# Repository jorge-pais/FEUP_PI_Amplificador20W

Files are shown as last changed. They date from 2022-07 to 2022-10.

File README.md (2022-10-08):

# FEUP PI Amplificador20W
 
20W Audio Amplifier circuit developed for the capstone project of the Bachelor in Electrical and Computer Enginnering course.
The power amplifier features 2 voltage gain stages and a Class AB output stage, along with a DC servo for low output DC offset, a power supply filter featuring a capacitance multiplier and an optional input network.

### PCB Front 3D view
PCBfront

### PCB Rear 3D view
PCBback

## Credits to:
David Rainho\
Gustavo Santos\
Inês Brandão\
Jorge Ribeiro\
Margarida Leal\
Rodrigo Santacomba\
Tiago Ribeiro

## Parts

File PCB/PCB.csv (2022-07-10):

Source: | C:\Users\Jorge Pais\OneDrive\Faculdade\3Ano\S2\ProjetoIntegrador\PCB\PCB.kicad_sch
Date: | 10/07/2022 21:21:08
Tool: | Eeschema (6.0.2)
Generator: | C:\Program Files\KiCad\6.0\bin\scripting\plugins/bom_csv_grouped_by_value.py
Component Count: | 85
Individual Components:
Item | Qty | Reference(s) | Value | LibPart | Footprint | Datasheet
 |  | C1 | 470n | Device:C | Capacitor_THT:C_Rect_L7.2mm_W3.0mm_P5.00mm_FKS2_FKP2_MKS2_MKP2 | ~
 |  | C2 | 100u | Device:C_Polarized | Capacitor_THT:CP_Radial_D5.0mm_P2.00mm | ~
 |  | C3 | 100u | Device:C_Polarized | Capacitor_THT:CP_Radial_D5.0mm_P2.00mm | ~
 |  | C4 | 2p2 | Device:C | Capacitor_THT:C_Disc_D3.8mm_W2.6mm_P2.50mm | ~
 |  | C5 | 100n | Device:C | Capacitor_THT:C_Disc_D5.1mm_W3.2mm_P5.00mm | ~
 |  | C6 | 100n | Device:C | Capacitor_THT:C_Disc_D5.1mm_W3.2mm_P5.00mm | ~
 |  | C7 | 470n | Device:C | Capacitor_THT:C_Rect_L7.2mm_W3.0mm_P5.00mm_FKS2_FKP2_MKS2_MKP2 | ~
 |  | C8 | 100u | Device:C_Polarized | Capacitor_THT:CP_Radial_D8.0mm_P3.50mm | ~
 |  | C9 | 100u | Device:C_Polarized | Capacitor_THT:CP_Radial_D8.0mm_P3.50mm | ~
 |  | C10 | 10u | Device:C_Polarized | Capacitor_THT:CP_Radial_D5.0mm_P2.00mm | ~
 |  | C11 | 10u | Device:C_Polarized | Capacitor_THT:CP_Radial_D5.0mm_P2.00mm | ~
 |  | C12 | 100n | Device:C | Capacitor_THT:C_Disc_D5.1mm_W3.2mm_P5.00mm | ~
 |  | C13 | 100n | Device:C | Capacitor_THT:C_Disc_D5.1mm_W3.2mm_P5.00mm | ~
 |  | C14 | 3n3 | Device:C | Capacitor_THT:C_Rect_L7.2mm_W2.5mm_P5.00mm_FKS2_FKP2_MKS2_MKP2 | ~
 |  | C15 | 10u | Device:C_Polarized | Capacitor_THT:CP_Radial_D5.0mm_P2.00mm | ~
 |  | C16 | 10u | Device:C_Polarized | Capacitor_THT:CP_Radial_D5.0mm_P2.00mm | ~
 |  | C17 | 47p | Device:C | Capacitor_THT:C_Disc_D4.3mm_W1.9mm_P5.00mm | ~
 |  | C18 | 220n | Device:C | Capacitor_THT:C_Rect_L7.0mm_W2.5mm_P5.00mm | ~
 |  | C19 | 100n | Device:C | Capacitor_THT:C_Rect_L13.0mm_W5.0mm_P10.00mm_FKS3_FKP3_MKS4 | ~
 |  | C20 | 100n | Device:C | Capacitor_THT:C_Disc_D5.1mm_W3.2mm_P5.00mm | ~
 |  | C21 | 100n | Device:C | Capacitor_THT:C_Disc_D5.1mm_W3.2mm_P5.00mm | ~
 |  | D1 | 1N914 | Diode:1N914 | Diode_THT:D_DO-35_SOD27_P7.62mm_Horizontal | http://www.vishay.com/docs/85622/1n914.pdf
 |  | D2 | 1N914 | Diode:1N914 | Diode_THT:D_DO-35_SOD27_P7.62mm_Horizontal | http://www.vishay.com/docs/85622/1n914.pdf
 |  | D3 | 1N4148 | Diode:1N4148 | Diode_THT:D_DO-35_SOD27_P7.62mm_Horizontal | https://assets.nexperia.com/documents/data-sheet/1N4148_1N4448.pdf
 |  | D4 | 1N4148 | Diode:1N4148 | Diode_THT:D_DO-35_SOD27_P7.62mm_Horizontal | https://assets.nexperia.com/documents/data-sheet/1N4148_1N4448.pdf
 |  | D5 | 1N4004 | Diode:1N4004 | Diode_THT:D_DO-41_SOD81_P10.16mm_Horizontal | http://www.vishay.com/docs/88503/1n4001.pdf
 |  | D6 | 1N4004 | Diode:1N4004 | Diode_THT:D_DO-41_SOD81_P10.16mm_Horizontal | http://www.vishay.com/docs/88503/1n4001.pdf
 |  | H1 | MountingHole_Pad | Mechanical:MountingHole_Pad | MountingHole:MountingHole_3.2mm_M3_Pad_Via | ~
 |  | H2 | MountingHole_Pad | Mechanical:MountingHole_Pad | MountingHole:MountingHole_3.2mm_M3_Pad_Via | ~
 |  | H3 | MountingHole_Pad | Mechanical:MountingHole_Pad | MountingHole:MountingHole_3.2mm_M3_Pad_Via | ~
 |  | H4 | MountingHole_Pad | Mechanical:MountingHole_Pad | MountingHole:MountingHole_3.2mm_M3_Pad_Via | ~
 |  | J1 | Screw_Terminal_01x03 | Connector:Screw_Terminal_01x03 | TerminalBlock:TerminalBlock_bornier-3_P5.08mm | ~
 |  | J2 | Conn_01x02 | Connector_Generic:Conn_01x02 | Connector_PinHeader_2.54mm:PinHeader_1x02_P2.54mm_Vertical | ~
 |  | J3 | Screw_Terminal_01x02 | Connector:Screw_Terminal_01x02 | TerminalBlock:TerminalBlock_bornier-2_P5.08mm | ~
 |  | Q1 | 2N3904 | Transistor_BJT:2N3904 | Package_TO_SOT_THT:TO-92_Inline | https://www.onsemi.com/pub/Collateral/2N3903-D.PDF
 |  | Q2 | 2N3906 | Transistor_BJT:2N3906 | Package_TO_SOT_THT:TO-92_Inline | https://www.onsemi.com/pub/Collateral/2N3906-D.PDF
 |  | Q3 | 2N4403 | Device:Q_PNP_EBC | Package_TO_SOT_THT:TO-92_Inline | ~
 |  | Q4 | 2N4401 | Device:Q_NPN_EBC | Package_TO_SOT_THT:TO-92_Inline | ~
 |  | Q5 | 2N4403 | Device:Q_PNP_EBC | Package_TO_SOT_THT:TO-92_Inline | ~
 |  | Q6 | 2N4401 | Device:Q_NPN_EBC | Package_TO_SOT_THT:TO-92_Inline | ~
 |  | Q7 | 2N4403 | Device:Q_PNP_EBC | Package_TO_SOT_THT:TO-92_Inline | ~
 |  | Q8 | 2N4403 | Device:Q_PNP_EBC | Package_TO_SOT_THT:TO-92_Inline | ~
 |  | Q9 | 2N4401 | Device:Q_NPN_EBC | Package_TO_SOT_THT:TO-92_Inline | ~
 |  | Q10 | 2N4403 | Device:Q_PNP_EBC | Package_TO_SOT_THT:TO-92_Inline | ~
 |  | Q11 | 2N4401 | Device:Q_NPN_EBC | Package_TO_SOT_THT:TO-92_Inline | ~
 |  | Q12 | 2N4401 | Device:Q_NPN_EBC | Package_TO_SOT_THT:TO-92_Inline | ~
 |  | Q13 | 2N5550 | Device:Q_NPN_EBC | Package_TO_SOT_THT:TO-92_Inline | ~
 |  | Q14 | 2N5401 | Device:Q_PNP_EBC | Package_TO_SOT_THT:TO-92_Inline | ~
 |  | Q15 | MJF15031 | Device:Q_PNP_BCE | Package_TO_SOT_THT:TO-220F-3_Vertical | ~
 |  | Q16 | MJF15030 | Device:Q_NPN_BCE | Package_TO_SOT_THT:TO-220F-3_Vertical | ~
 |  | R1 | 330k | Device:R | Resistor_THT:R_Axial_DIN0207_L6.3mm_D2.5mm_P7.62mm_Horizontal | ~
 |  | R2 | 1k | Device:R | Resistor_THT:R_Axial_DIN0207_L6.3mm_D2.5mm_P7.62mm_Horizontal | ~
 |  | R3 | 10 | Device:R | Resistor_THT:R_Axial_DIN0207_L6.3mm_D2.5mm_P7.62mm_Horizontal | ~
 |  | R4 | 10 | Device:R | Resistor_THT:R_Axial_DIN0207_L6.3mm_D2.5mm_P7.62mm_Horizontal | ~
 |  | R5 | 100 | Device:R | Resistor_THT:R_Axial_DIN0207_L6.3mm_D2.5mm_P7.62mm_Horizontal | ~
 |  | R6 | 8k2 | Device:R | Resistor_THT:R_Axial_DIN0207_L6.3mm_D2.5mm_P7.62mm_Horizontal | ~
 |  | R7 | 330k | Device:R | Resistor_THT:R_Axial_DIN0207_L6.3mm_D2.5mm_P7.62mm_Horizontal | ~
 |  | R8 | 330k | Device:R | Resistor_THT:R_Axial_DIN0207_L6.3mm_D2.5mm_P7.62mm_Horizontal | ~
 |  | R9 | 220 | Device:R | Resistor_THT:R_Axial_DIN0207_L6.3mm_D2.5mm_P7.62mm_Horizontal | ~
 |  | R10 | 22k | Device:R | Resistor_THT:R_Axial_DIN0207_L6.3mm_D2.5mm_P7.62mm_Horizontal | ~
 |  | R11 | 22k | Device:R | Resistor_THT:R_Axial_DIN0207_L6.3mm_D2.5mm_P7.62mm_Horizontal | ~
 |  | R12 | 220 | Device:R | Resistor_THT:R_Axial_DIN0207_L6.3mm_D2.5mm_P7.62mm_Horizontal | ~
 |  | R13 | 100k | Device:R | Resistor_THT:R_Axial_DIN0207_L6.3mm_D2.5mm_P7.62mm_Horizontal | ~
 |  | R14 | 50 | Device:R | Resistor_THT:R_Axial_DIN0207_L6.3mm_D2.5mm_P7.62mm_Horizontal | ~
 |  | R15 | 4.7 | Device:R | Resistor_THT:R_Axial_DIN0207_L6.3mm_D2.5mm_P7.62mm_Horizontal | ~
 |  | R16 | 330 | Device:R | Resistor_THT:R_Axial_DIN0207_L6.3mm_D2.5mm_P7.62mm_Horizontal | ~
 |  | R17 | 180 | Device:R | Resistor_THT:R_Axial_DIN0207_L6.3mm_D2.5mm_P7.62mm_Horizontal | ~
 |  | R18 | 100 | Device:R | Resistor_THT:R_Axial_DIN0207_L6.3mm_D2.5mm_P7.62mm_Horizontal | ~
 |  | R19 | 8k2 | Device:R | Resistor_THT:R_Axial_DIN0207_L6.3mm_D2.5mm_P7.62mm_Horizontal | ~
 |  | R20 | 330 | Device:R | Resistor_THT:R_Axial_DIN0207_L6.3mm_D2.5mm_P7.62mm_Horizontal | ~
 |  | R21 | 180 | Device:R | Resistor_THT:R_Axial_DIN0207_L6.3mm_D2.5mm_P7.62mm_Horizontal | ~
 |  | R22 | 15k | Device:R | Resistor_THT:R_Axial_DIN0207_L6.3mm_D2.5mm_P7.62mm_Horizontal | ~
 |  | R23 | 15k | Device:R | Resistor_THT:R_Axial_DIN0207_L6.3mm_D2.5mm_P7.62mm_Horizontal | ~
 |  | R24 | 820 | Device:R | Resistor_THT:R_Axial_DIN0207_L6.3mm_D2.5mm_P7.62mm_Horizontal | ~
 |  | R25 | 68 | Device:R | Resistor_THT:R_Axial_DIN0207_L6.3mm_D2.5mm_P7.62mm_Horizontal | ~
 |  | R26 | 820 | Device:R | Resistor_THT:R_Axial_DIN0207_L6.3mm_D2.5mm_P7.62mm_Horizontal | ~
 |  | R27 | 390 | Device:R | Resistor_THT:R_Axial_DIN0207_L6.3mm_D2.5mm_P7.62mm_Horizontal | ~
 |  | R28 | 33 | Device:R | Resistor_THT:R_Axial_DIN0207_L6.3mm_D2.5mm_P7.62mm_Horizontal | ~
 |  | R29 | 330 | Device:R | Resistor_THT:R_Axial_DIN0207_L6.3mm_D2.5mm_P7.62mm_Horizontal | ~
 |  | R30 | 330 | Device:R | Resistor_THT:R_Axial_DIN0207_L6.3mm_D2.5mm_P7.62mm_Horizontal | ~
 |  | R31 | 0.22 | Device:R | Resistor_THT:R_Axial_DIN0617_L17.0mm_D6.0mm_P25.40mm_Horizontal | ~
 |  | R32 | 0.22 | Device:R | Resistor_THT:R_Axial_DIN0617_L17.0mm_D6.0mm_P25.40mm_Horizontal | ~
 |  | R33 | 5 | Device:R | Resistor_THT:R_Axial_DIN0617_L17.0mm_D6.0mm_P20.32mm_Horizontal | ~
 |  | RV1 | 1k | Device:R_Potentiometer | Potentiometer_THT:Potentiometer_Bourns_3296W_Vertical | ~
 |  | U1 | OPA1641 | Amplifier_Operational:OPA1641 | Package_SO:SOIC-8_3.9x4.9mm_P1.27mm | http://www.ti.com/lit/ds/symlink/opa1641.pdf
Collated Components:
Item | Qty | Reference(s) | Value | LibPart | Footprint | Datasheet
1 | 2 | C1, C7 | 470n | Device:C | Capacitor_THT:C_Rect_L7.2mm_W3.0mm_P5.00mm_FKS2_FKP2_MKS2_MKP2 | ~
2 | 2 | C2, C3 | 100u | Device:C_Polarized | Capacitor_THT:CP_Radial_D5.0mm_P2.00mm | ~
3 | 1 | C4 | 2p2 | Device:C | Capacitor_THT:C_Disc_D3.8mm_W2.6mm_P2.50mm | ~
4 | 6 | C5, C6, C12, C13, C20, C21 | 100n | Device:C | Capacitor_THT:C_Disc_D5.1mm_W3.2mm_P5.00mm | ~
5 | 2 | C8, C9 | 100u | Device:C_Polarized | Capacitor_THT:CP_Radial_D8.0mm_P3.50mm | ~
6 | 4 | C10, C11, C15, C16 | 10u | Device:C_Polarized | Capacitor_THT:CP_Radial_D5.0mm_P2.00mm | ~
7 | 1 | C14 | 3n3 | Device:C | Capacitor_THT:C_Rect_L7.2mm_W2.5mm_P5.00mm_FKS2_FKP2_MKS2_MKP2 | ~
8 | 1 | C17 | 47p | Device:C | Capacitor_THT:C_Disc_D4.3mm_W1.9mm_P5.00mm | ~
9 | 1 | C18 | 220n | Device:C | Capacitor_THT:C_Rect_L7.0mm_W2.5mm_P5.00mm | ~
10 | 1 | C19 | 100n | Device:C | Capacitor_THT:C_Rect_L13.0mm_W5.0mm_P10.00mm_FKS3_FKP3_MKS4 | ~
11 | 2 | D1, D2 | 1N914 | Diode:1N914 | Diode_THT:D_DO-35_SOD27_P7.62mm_Horizontal | http://www.vishay.com/docs/85622/1n914.pdf
12 | 2 | D3, D4 | 1N4148 | Diode:1N4148 | Diode_THT:D_DO-35_SOD27_P7.62mm_Horizontal | https://assets.nexperia.com/documents/data-sheet/1N4148_1N4448.pdf
13 | 2 | D5, D6 | 1N4004 | Diode:1N4004 | Diode_THT:D_DO-41_SOD81_P10.16mm_Horizontal | http://www.vishay.com/docs/88503/1n4001.pdf
14 | 4 | H1, H2, H3, H4 | MountingHole_Pad | Mechanical:MountingHole_Pad | MountingHole:MountingHole_3.2mm_M3_Pad_Via | ~
15 | 1 | J1 | Screw_Terminal_01x03 | Connector:Screw_Terminal_01x03 | TerminalBlock:TerminalBlock_bornier-3_P5.08mm | ~
16 | 1 | J2 | Conn_01x02 | Connector_Generic:Conn_01x02 | Connector_PinHeader_2.54mm:PinHeader_1x02_P2.54mm_Vertical | ~
17 | 1 | J3 | Screw_Terminal_01x02 | Connector:Screw_Terminal_01x02 | TerminalBlock:TerminalBlock_bornier-2_P5.08mm | ~
18 | 1 | Q1 | 2N3904 | Transistor_BJT:2N3904 | Package_TO_SOT_THT:TO-92_Inline | https://www.onsemi.com/pub/Collateral/2N3903-D.PDF
19 | 1 | Q2 | 2N3906 | Transistor_BJT:2N3906 | Package_TO_SOT_THT:TO-92_Inline | https://www.onsemi.com/pub/Collateral/2N3906-D.PDF
20 | 5 | Q3, Q5, Q7, Q8, Q10 | 2N4403 | Device:Q_PNP_EBC | Package_TO_SOT_THT:TO-92_Inline | ~
21 | 5 | Q4, Q6, Q9, Q11, Q12 | 2N4401 | Device:Q_NPN_EBC | Package_TO_SOT_THT:TO-92_Inline | ~
22 | 1 | Q13 | 2N5550 | Device:Q_NPN_EBC | Package_TO_SOT_THT:TO-92_Inline | ~
23 | 1 | Q14 | 2N5401 | Device:Q_PNP_EBC | Package_TO_SOT_THT:TO-92_Inline | ~
24 | 1 | Q15 | MJF15031 | Device:Q_PNP_BCE | Package_TO_SOT_THT:TO-220F-3_Vertical | ~
25 | 1 | Q16 | MJF15030 | Device:Q_NPN_BCE | Package_TO_SOT_THT:TO-220F-3_Vertical | ~
26 | 3 | R1, R7, R8 | 330k | Device:R | Resistor_THT:R_Axial_DIN0207_L6.3mm_D2.5mm_P7.62mm_Horizontal | ~
27 | 1 | R2 | 1k | Device:R | Resistor_THT:R_Axial_DIN0207_L6.3mm_D2.5mm_P7.62mm_Horizontal | ~
28 | 2 | R3, R4 | 10 | Device:R | Resistor_THT:R_Axial_DIN0207_L6.3mm_D2.5mm_P7.62mm_Horizontal | ~
29 | 2 | R5, R18 | 100 | Device:R | Resistor_THT:R_Axial_DIN0207_L6.3mm_D2.5mm_P7.62mm_Horizontal | ~
30 | 2 | R6, R19 | 8k2 | Device:R | Resistor_THT:R_Axial_DIN0207_L6.3mm_D2.5mm_P7.62mm_Horizontal | ~
31 | 2 | R9, R12 | 220 | Device:R | Resistor_THT:R_Axial_DIN0207_L6.3mm_D2.5mm_P7.62mm_Horizontal | ~
32 | 2 | R10, R11 | 22k | Device:R | Resistor_THT:R_Axial_DIN0207_L6.3mm_D2.5mm_P7.62mm_Horizontal | ~
33 | 1 | R13 | 100k | Device:R | Resistor_THT:R_Axial_DIN0207_L6.3mm_D2.5mm_P7.62mm_Horizontal | ~
34 | 1 | R14 | 50 | Device:R | Resistor_THT:R_Axial_DIN0207_L6.3mm_D2.5mm_P7.62mm_Horizontal | ~
35 | 1 | R15 | 4.7 | Device:R | Resistor_THT:R_Axial_DIN0207_L6.3mm_D2.5mm_P7.62mm_Horizontal | ~
36 | 4 | R16, R20, R29, R30 | 330 | Device:R | Resistor_THT:R_Axial_DIN0207_L6.3mm_D2.5mm_P7.62mm_Horizontal | ~
37 | 2 | R17, R21 | 180 | Device:R | Resistor_THT:R_Axial_DIN0207_L6.3mm_D2.5mm_P7.62mm_Horizontal | ~
38 | 2 | R22, R23 | 15k | Device:R | Resistor_THT:R_Axial_DIN0207_L6.3mm_D2.5mm_P7.62mm_Horizontal | ~
39 | 2 | R24, R26 | 820 | Device:R | Resistor_THT:R_Axial_DIN0207_L6.3mm_D2.5mm_P7.62mm_Horizontal | ~
40 | 1 | R25 | 68 | Device:R | Resistor_THT:R_Axial_DIN0207_L6.3mm_D2.5mm_P7.62mm_Horizontal | ~
41 | 1 | R27 | 390 | Device:R | Resistor_THT:R_Axial_DIN0207_L6.3mm_D2.5mm_P7.62mm_Horizontal | ~
42 | 1 | R28 | 33 | Device:R | Resistor_THT:R_Axial_DIN0207_L6.3mm_D2.5mm_P7.62mm_Horizontal | ~
43 | 2 | R31, R32 | 0.22 | Device:R | Resistor_THT:R_Axial_DIN0617_L17.0mm_D6.0mm_P25.40mm_Horizontal | ~
44 | 1 | R33 | 5 | Device:R | Resistor_THT:R_Axial_DIN0617_L17.0mm_D6.0mm_P20.32mm_Horizontal | ~
45 | 1 | RV1 | 1k | Device:R_Potentiometer | Potentiometer_THT:Potentiometer_Bourns_3296W_Vertical | ~
46 | 1 | U1 | OPA1641 | Amplifier_Operational:OPA1641 | Package_SO:SOIC-8_3.9x4.9mm_P1.27mm | http://www.ti.com/lit/ds/symlink/opa1641.pdf

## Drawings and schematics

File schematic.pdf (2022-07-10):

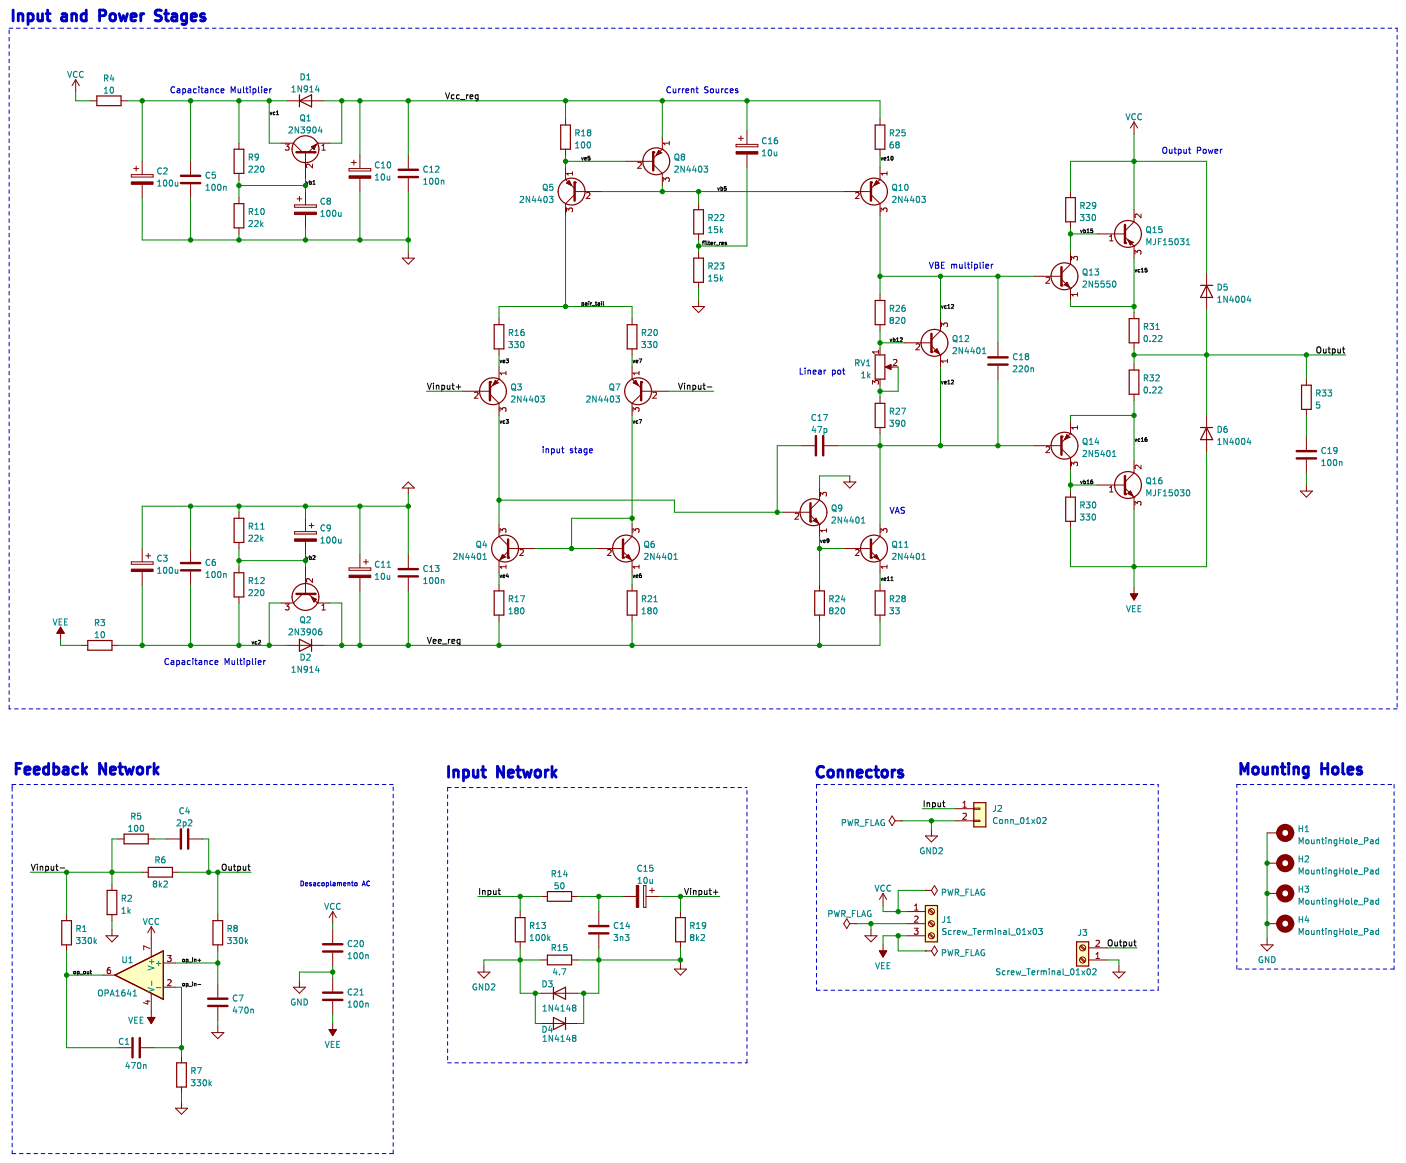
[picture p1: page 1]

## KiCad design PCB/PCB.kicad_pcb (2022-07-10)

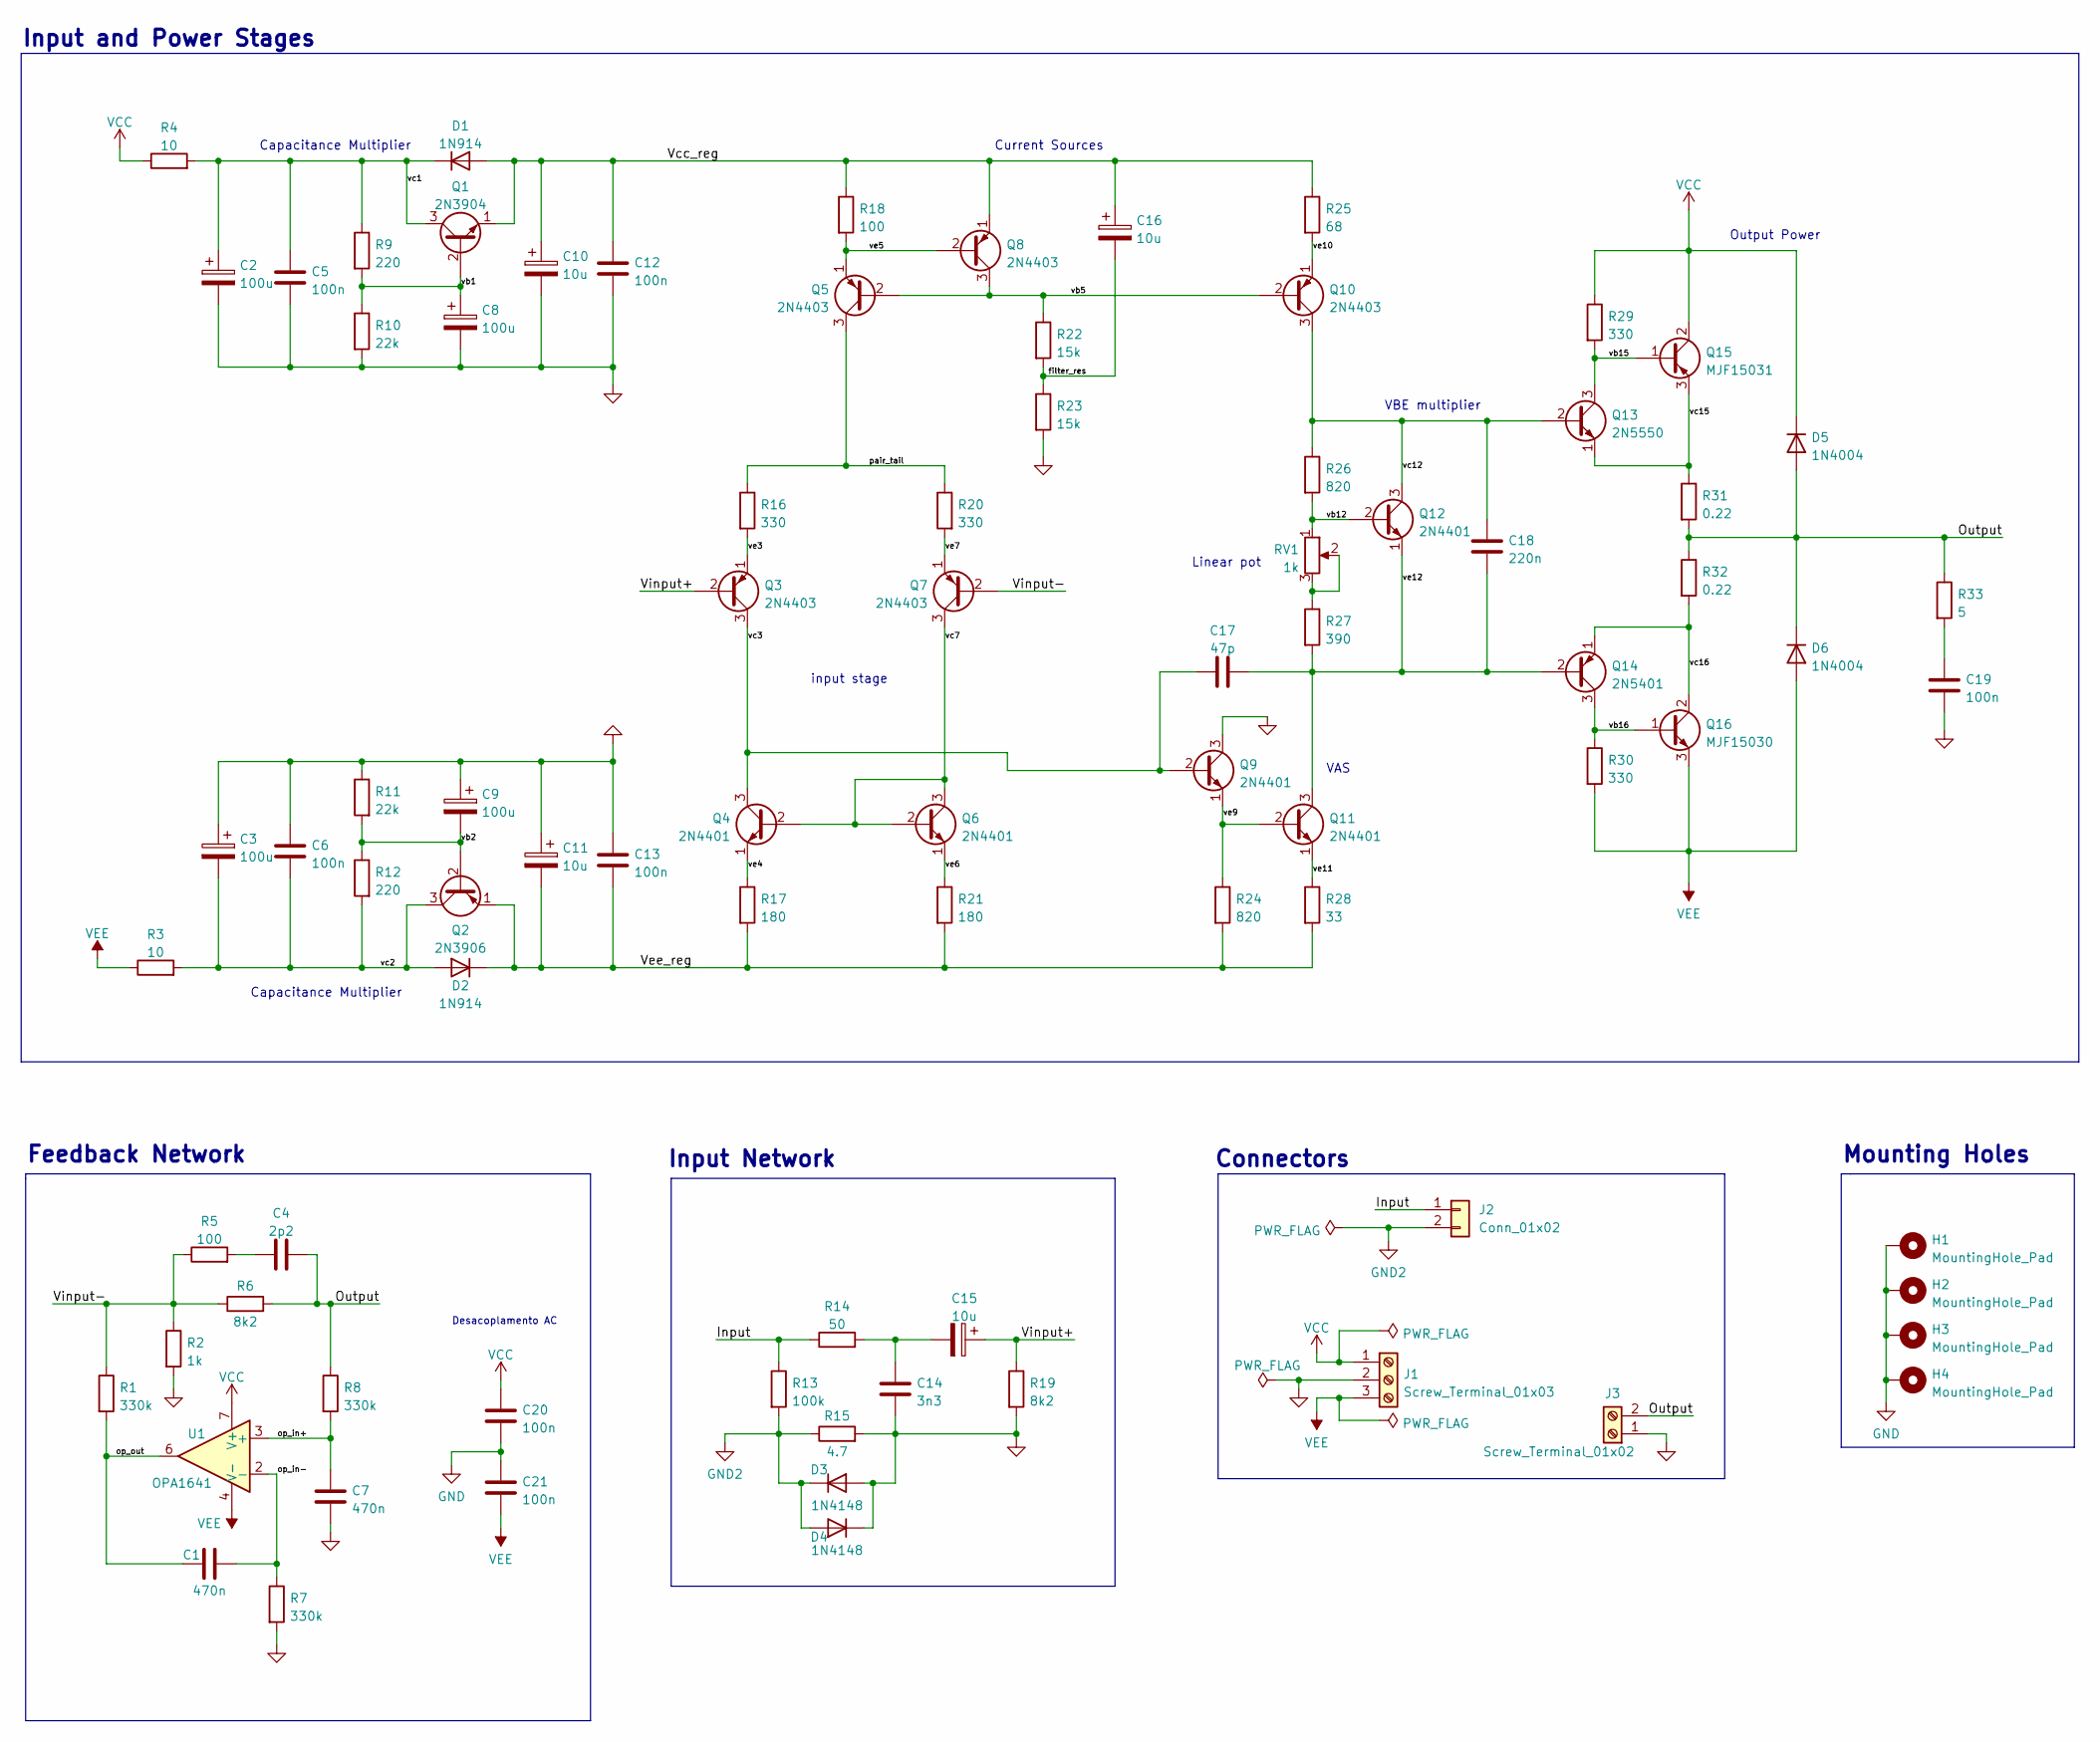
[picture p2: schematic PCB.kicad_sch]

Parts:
C1, C7: 470n; C_Rect_L7.2mm_W3.0mm_P5.00mm_FKS2_FKP2_MKS2_MKP2
C2, C3: 100u; CP_Radial_D5.0mm_P2.00mm
C4: 2p2; C_Disc_D3.8mm_W2.6mm_P2.50mm
C5, C6, C12, C13, C20, C21: 100n; C_Disc_D5.1mm_W3.2mm_P5.00mm
C8, C9: 100u; CP_Radial_D8.0mm_P3.50mm
C10, C11, C15, C16: 10u; CP_Radial_D5.0mm_P2.00mm
C14: 3n3; C_Rect_L7.2mm_W2.5mm_P5.00mm_FKS2_FKP2_MKS2_MKP2
C17: 47p; C_Disc_D4.3mm_W1.9mm_P5.00mm
C18: 220n; C_Rect_L7.0mm_W2.5mm_P5.00mm
C19: 100n; C_Rect_L13.0mm_W5.0mm_P10.00mm_FKS3_FKP3_MKS4
D1, D2: 1N914; D_DO-35_SOD27_P7.62mm_Horizontal
D3, D4: 1N4148; D_DO-35_SOD27_P7.62mm_Horizontal
D5, D6: 1N4004; D_DO-41_SOD81_P10.16mm_Horizontal
H1, H2, H3, H4: MountingHole_Pad; MountingHole_3.2mm_M3_Pad_Via
J1: Screw_Terminal_01x03; TerminalBlock_bornier-3_P5.08mm
J2: Conn_01x02; PinHeader_1x02_P2.54mm_Vertical
J3: Screw_Terminal_01x02; TerminalBlock_bornier-2_P5.08mm
Q1: 2N3904; TO-92_Inline
Q2: 2N3906; TO-92_Inline
Q3, Q5, Q7, Q8, Q10: 2N4403; TO-92_Inline
Q4, Q6, Q9, Q11, Q12: 2N4401; TO-92_Inline
Q13: 2N5550; TO-92_Inline
Q14: 2N5401; TO-92_Inline
Q15: MJF15031; TO-220F-3_Vertical
Q16: MJF15030; TO-220F-3_Vertical
R1, R7, R8: 330k; R_Axial_DIN0207_L6.3mm_D2.5mm_P7.62mm_Horizontal
R2: 1k; R_Axial_DIN0207_L6.3mm_D2.5mm_P7.62mm_Horizontal
R3, R4: 10; R_Axial_DIN0207_L6.3mm_D2.5mm_P7.62mm_Horizontal
R5, R18: 100; R_Axial_DIN0207_L6.3mm_D2.5mm_P7.62mm_Horizontal
R6, R19: 8k2; R_Axial_DIN0207_L6.3mm_D2.5mm_P7.62mm_Horizontal
R9, R12: 220; R_Axial_DIN0207_L6.3mm_D2.5mm_P7.62mm_Horizontal
R10, R11: 22k; R_Axial_DIN0207_L6.3mm_D2.5mm_P7.62mm_Horizontal
R13: 100k; R_Axial_DIN0207_L6.3mm_D2.5mm_P7.62mm_Horizontal
R14: 50; R_Axial_DIN0207_L6.3mm_D2.5mm_P7.62mm_Horizontal
R15: 4.7; R_Axial_DIN0207_L6.3mm_D2.5mm_P7.62mm_Horizontal
R16, R20, R29, R30: 330; R_Axial_DIN0207_L6.3mm_D2.5mm_P7.62mm_Horizontal
R17, R21: 180; R_Axial_DIN0207_L6.3mm_D2.5mm_P7.62mm_Horizontal
R22, R23: 15k; R_Axial_DIN0207_L6.3mm_D2.5mm_P7.62mm_Horizontal
R24, R26: 820; R_Axial_DIN0207_L6.3mm_D2.5mm_P7.62mm_Horizontal
R25: 68; R_Axial_DIN0207_L6.3mm_D2.5mm_P7.62mm_Horizontal
R27: 390; R_Axial_DIN0207_L6.3mm_D2.5mm_P7.62mm_Horizontal
R28: 33; R_Axial_DIN0207_L6.3mm_D2.5mm_P7.62mm_Horizontal
R31, R32: 0.22; R_Axial_DIN0617_L17.0mm_D6.0mm_P25.40mm_Horizontal
R33: 5; R_Axial_DIN0617_L17.0mm_D6.0mm_P20.32mm_Horizontal
RV1: 1k; Potentiometer_Bourns_3296W_Vertical
U1: OPA1641; SOIC-8_3.9x4.9mm_P1.27mm

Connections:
/Input: J2.1, R13.1, R14.1
/Output: C4.2, D5.2 (A), D6.1 (K), J3.2, R6.2, R8.1, R31.2, R32.1, R33.1
/Vcc_reg: C10.1, C12.1, C16.1, D1.2 (A), Q1.1 (E), Q8.1 (E), R18.1, R25.1
/Vee_reg: C11.2, C13.2, D2.1 (K), Q2.1 (E), R17.2, R21.2, R24.2, R28.2
/Vinput+: C15.1, Q3.2 (B), R19.1
/Vinput-: Q7.2 (B), R1.1, R2.1, R5.1, R6.1
/filter_res: C16.2, R22.2, R23.1
/op_in+: C7.1, R8.2, U1.3 (+)
/op_in-: C1.2, R7.1, U1.2 (-)
/op_out: C1.1, R1.2, U1.6
/pair_tail: Q5.3 (C), R16.1, R20.1
/vb1: C8.1, Q1.2 (B), R9.2, R10.1
/vb2: C9.2, Q2.2 (B), R11.2, R12.1
/vb5: Q5.2 (B), Q8.3 (C), Q10.2 (B), R22.1
/vb12: Q12.2 (B), R26.2, RV1.1
/vb15: Q13.3 (C), Q15.1 (B), R29.2
/vb16: Q14.3 (C), Q16.1 (B), R30.1
/vc1: C2.1, C5.1, D1.1 (K), Q1.3 (C), R4.2, R9.1
/vc2: C3.2, C6.2, D2.2 (A), Q2.3 (C), R3.2, R12.2
/vc3: C17.1, Q3.3 (C), Q4.3 (C), Q9.2 (B)
/vc7: Q4.2 (B), Q6.2 (B), Q6.3 (C), Q7.3 (C)
/vc12: C18.1, Q10.3 (C), Q12.3 (C), Q13.2 (B), R26.1
/vc15: Q13.1 (E), Q15.3 (E), R31.1
/vc16: Q14.1 (E), Q16.2 (C), R32.2
/ve3: Q3.1 (E), R16.2
/ve4: Q4.1 (E), R17.1
/ve5: Q5.1 (E), Q8.2 (B), R18.2
/ve6: Q6.1 (E), R21.1
/ve7: Q7.1 (E), R20.2
/ve9: Q9.1 (E), Q11.2 (B), R24.1
/ve10: Q10.1 (E), R25.2
/ve11: Q11.1 (E), R28.1
/ve12: C17.2, C18.2, Q11.3 (C), Q12.1 (E), Q14.2 (B), R27.2
GND: C2.2, C3.1, C5.2, C6.1, C7.2, C8.2, C9.1, C10.2, C11.1, C12.2, C13.1, C14.2, C19.2, C20.2, C21.1, D3.2 (A), D4.1 (K), H1.1, H2.1, H3.1, H4.1, J1.2, J3.1, Q9.3 (C), R2.2, R7.2, R10.2, R11.1, R15.2, R19.2, R23.2
GND2: D3.1 (K), D4.2 (A), J2.2, R13.2, R15.1
unnamed: C4.1, R5.2
unnamed: C14.1, C15.2, R14.2
unnamed: C19.1, R33.2
unnamed: R27.1, RV1.2, RV1.3
VCC: C20.1, D5.1 (K), J1.1, Q15.2 (C), R4.1, R29.1, U1.7 (V+)
VEE: C21.2, D6.2 (A), J1.3, Q16.3 (E), R3.1, R30.2, U1.4 (V-)

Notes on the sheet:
Feedback Network
Mounting Holes
Desacoplamento AC
Output Power
input stage
Capacitance Multiplier
VAS
Input and Power Stages
VBE multiplier
Connectors
Input Network
Current Sources
Linear pot

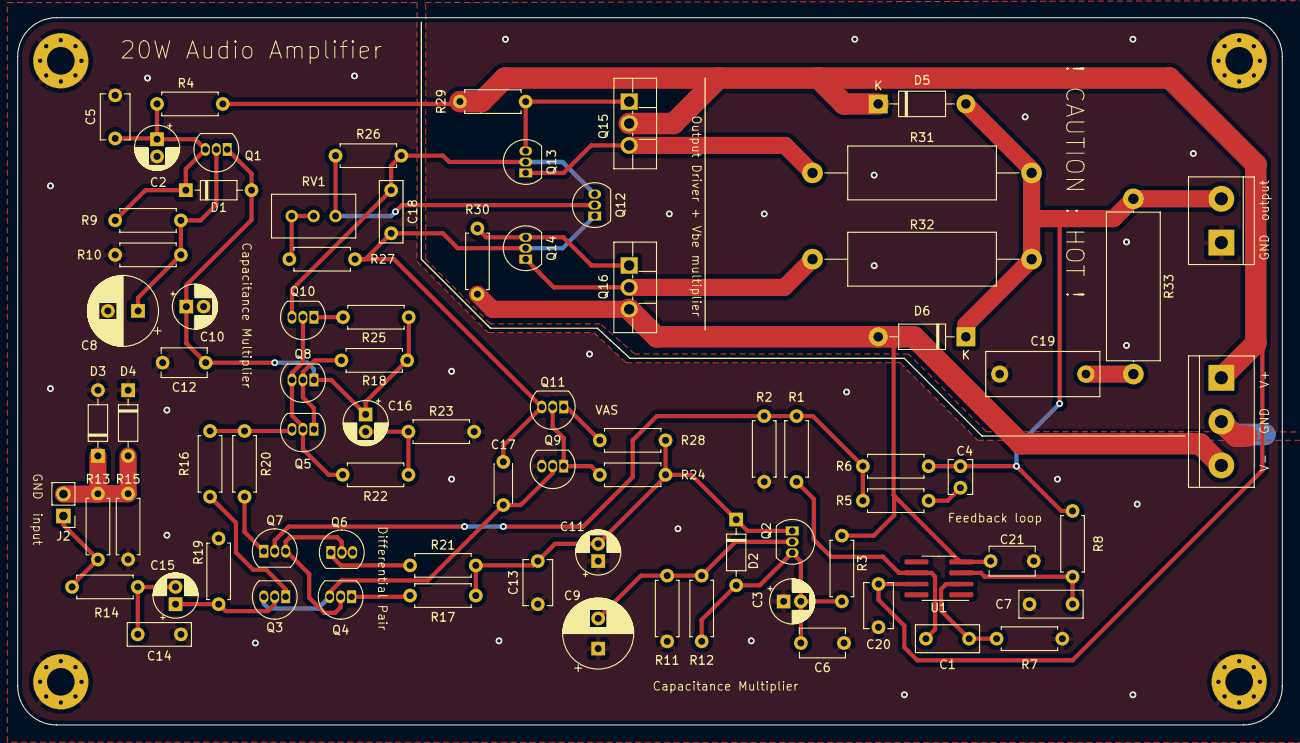
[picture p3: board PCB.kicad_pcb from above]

Board: 2 copper layers, 146.6 x 82.0 mm, 85 parts (0 on the bottom side), 41 nets.
